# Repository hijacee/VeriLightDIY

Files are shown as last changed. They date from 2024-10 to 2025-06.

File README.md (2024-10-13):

# VeriLightDIY
A DIY Wifi Version of the FinishLynx "VeriLight" that is controllable via the original .lss file. 

## Hardware
You'll need:

- an ESP32 with onboard Wifi, I used an ESP32-WROOM-32U DevKit board from AliExpress
- Some LED Matrices, I used two WS2812b 8x8 5V Grids
- an optional external Wifi antenna to enhance the wifi reception
- an optional mini OLED Screen to see the current configuration, I used an 0.96" OLED Display SSD1306 I2C 128x64 module 4 pin
- an optional momentary push button

## 3D CAD files
The first prototype consists of 4 parts. Feel free to edit, adapt and print those parts for your needs.

- LED_Grid_stl is designed to fit 2 8x8 led matrixes quite tightly
- Cap_Display.stl has a cutout for the OLED display and the wifi antenna with a hexagonal cutout
- ESP_devboard_holder.stl is the middle part to hold the esp loosely in place (upright, USB connector facing downwards), here is definitely room for improvement
- Base_small.stl is the foot/base for the whole setup. In future iterations I could imagine to make this part larger to fit a powerbank directly into the base

## Connection Diagram
Pin 12: Data-Pin LED Matrix
Pin 13: Reset Button
Pin 21: SDA Pin (OLED Screen)
Pin 22: SCL Pin (OLED Screen)

It is very well possible to power the LED Matrices (at least 2x 8x8 Matrices) via the 5V Pin of the ESP. You could also power the matrices directly via a separate +5V source (such as parallel to the the ESP from a USB Powerbank)

The following diagram shows the connectio (note that the LED matrix depicted here is a 4 Pin, I used a 3 Pin with just +5V, GND and DATA).



## How to use the Light
### Network connection
You will need to set up a Wifi network that is also part of the PC you're running FinishLynx on. The Wifi-Router / AccessPoint you are using should be using DHCP to allocate IP addresses to new devices.

On the first start, the Light will go into access point (AP) Mode, as there are no known networks around. It will automatically broadcast an own wifi network named "ReadyLight_AP". Connect to the network with device of your choice - the default passwort is "12345678". Both is adaptable in Line 312 of the code. 
If your device is not directly redirected to the settings page, open a browser and type 192.168.4.1 (as the default Wifi-Manager IP).
The SSID and the IP address of the settings page are also displayed on the OLED display during AP-mode.
In the settings page you can scan for available networks. Chose your network from the list, enter the password if needed and save the configuration. The System will reboot and always connect automatically to the assigned network, if available. It will then also show it's current IP address on the OLED Screen as well as the Port the Light is listening for connection from FinishLynx.

To change the network properties or the FinishLynx Port, you need to re-enter the AP-mode. This is done in pressing the button within three seconds of the boot-up sequence.
If the last configured network is not available, the Light will also boot into AP-mode.



### FinishLynx Setup
The Light is configured as TCP server. To add the Light, follow these steps:
1. In FinishLynx, go to **Scoreboard | Options…**
2. Click **New**.
3. Script: **VeriLight_Ready.lss**
4. Serial Port: **Network(connect)**
   1. Port: **10000** (default, can be changed in the Configuration-Page of the Light, shown on the OLED screen)
   2. IP address: **depending on your network**, shown on the OLED screen
5. Running Time: **Normal**
6. Results: **Off**
7. Click **Ok** and restart FinishLynx.

### Operation
As long as the Light is connected to the network, it will display it's IP address and Port on the OLED display. 
If there is no TCP connection established, the LEDs blink yellow in an one second interval. When FinishLynx connects to that light, the blinking stops and the OLED displays "CLIENT CONNECTED". If, for any reason (network out of range, FinishLynx is closed etc.), the TCP connection breaks, the display says "CLIENT DISCONNECTED" and the LEDs start blinking yellow again. So you an anyone can tell immediately, that something is wrong.

  

The behaviour of the Light is set through the original VeryLight.lss from Finishlynx. You can adapt this lss-script to your needs. In the lss you will find commands that look similar to this:

~~~
;;TimeArmed
\11\00\=0\41\42\44\00\00\07\04\04\04\04\04\01\00
\11\00\=1
~~~

Note that the bytes after `\11\00\=0\` contain the relevant information for the DIY as well as the original VeriLynx Hardware by Patlite. Look in the orignal manual for deeper context: [Patlite LA6-POE Manual](https://docs.rs-online.com/ff50/0900766b8167c578.pdf) 

The seventh byte (in the case above, the first **04**) sets the color for the entire DIY Light according to the following table (same as original Patlite color palette):

| Seventh byte | Color |
| --- | --- |
| 00 | Black (off) |
| 01 | Red |
| 02 | Gold / Amber |
| 03 | Green-Yellow / Lemon |
| 04 | Green |
| 05 | Sky-blue |
| 06 | Blue |
| 07 | Purple |
| 08 | Pink |
| 09 | White |
| other | Black (off) |

Additionaly you can enable blinking of the light with the status of the 12th byte. If it is a **01**, blinking is enabled, if it is a **00**, blinking is disabled. Please note, that currently blinking does not work, when FinishLynx updates the output of the "scoreboard" every second or faster.

## Real life images





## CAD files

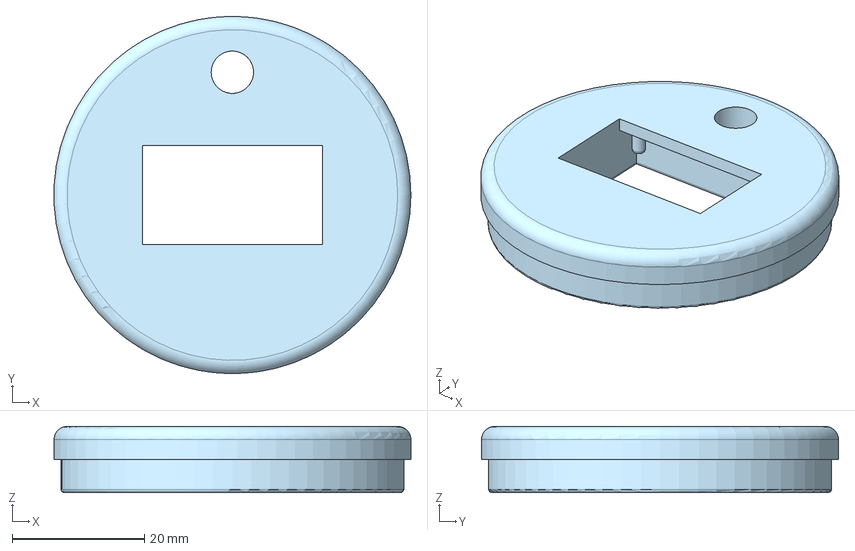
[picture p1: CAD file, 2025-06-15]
CAD_files/STEP/Cap_Display.step
54.0 x 54.0 x 10.0 mm

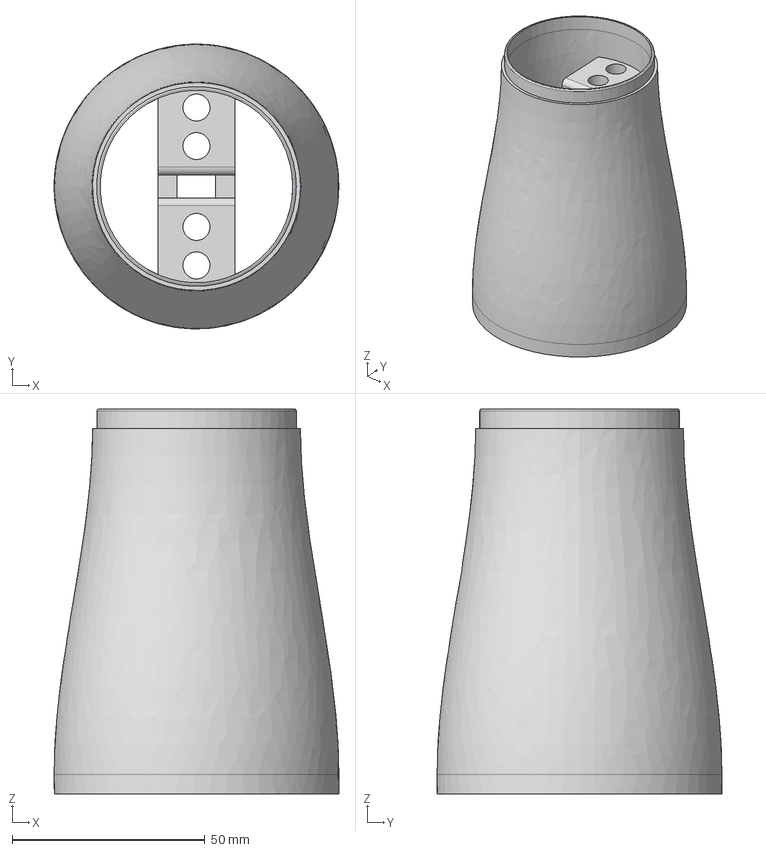
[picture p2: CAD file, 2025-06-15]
CAD_files/STEP/ESP_devboard_holder.step
74.0 x 74.0 x 100.0 mm

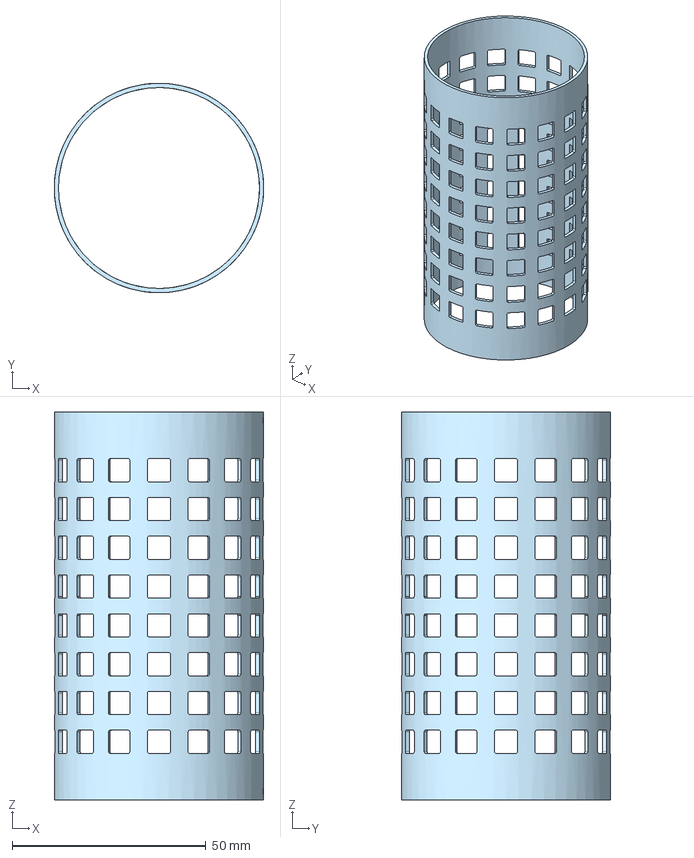
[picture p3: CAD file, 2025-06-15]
CAD_files/STEP/LED_Grid.step
54.0 x 54.0 x 100.0 mm

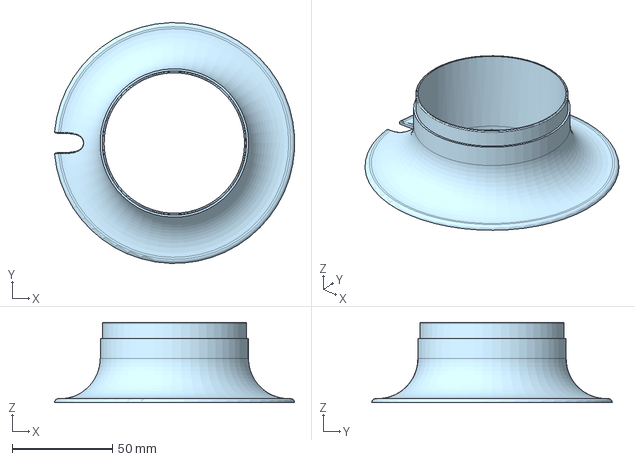
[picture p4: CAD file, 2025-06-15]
CAD_files/STEP/Base_small.step
119.6 x 120.0 x 40.0 mm

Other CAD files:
CAD_files/Base_small.stl
CAD_files/Cap_Display.stl
CAD_files/ESP_devboard_holder.stl
CAD_files/LED_Grid.stl

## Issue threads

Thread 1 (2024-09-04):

Blinking not working in time running / ready

hijacee, 2024-09-04:
The blinking command is not working during time running / ready state. This is due to the reason that the time / command is sent every 0.1 sec from lynx, triggering the function every single time again from start, so the timer does not have the chance to reach the 1 sec blinking interval.

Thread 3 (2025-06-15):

Fusion/Design files

pwae, 2025-06-15:
Hi There!

Love what you have made. I was just hoping if I could get a copy of the CAD files you had, so i can modify a few of the components (without reversing engineering the STL files!).

(e.g. my screen is a bit smaller, and i'm going to use a POE ESP32 board instead of a USB.

Cheers,
Scott

hijacee, 2025-06-15:
Hi Scott!

Thanks!
I provided the STEP files in the CAD folder. However, as I used Onshape instead of Fusion, I do not have native Fusion file formats available. Let me know, if you need another file format.

Cheers,
Christoph

pwae, 2025-06-16:
This is lovely! thank you so much

Scott

Closed 2025-06-16.

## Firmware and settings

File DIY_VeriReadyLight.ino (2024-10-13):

/*
  DIY VeriLight / ReadyLight for FinishLynx
  by Christoph, 2024
  
  Saves data in JSON file on ESP32
  Uses SPIFFS
  
  The Wifi-Manager functions are based on Bills codes at DroneBot Workshop
  https://dronebotworkshop.com/wifimanager/
 
  Functions based upon sketch by Brian Lough
  https://github.com/witnessmenow/ESP32-WiFi-Manager-Examples
*/
#define FASTLED_INTERNAL
 
// Include Libraries
 
#include <WiFi.h>         // WiFi Library
#include <FS.h>           // File System Library
#include <SPIFFS.h>       // SPI Flash Syetem Library
#include <WiFiManager.h>  // WiFiManager Library
#include <ArduinoJson.h>  // Arduino JSON library
#include <FastLED.h>      // LED Matrix Library
#include <Wire.h>         // 2 Wire communication
#include <Adafruit_GFX.h> // Library for Screen
#include <Adafruit_SSD1306.h> // Library for OLED Screen

#define ESP_DRD_USE_SPIFFS true
#define DATA_PIN 12                             // Define LED-Matrix Data Pin
#define TRIGGER_PIN 13                          // Define Wifi-Reset PIN
#define NUM_LEDS 128                            // Define LED-Matrix Data Pin
#define JSON_CONFIG_FILE "/test_config.json"    // JSON configuration file
#define SCREEN_WIDTH 128                        // OLED display width, in pixels
#define SCREEN_HEIGHT 64                        // OLED display height, in pixels
 
// Flag for saving data
bool shouldSaveConfig = false;
 
// Variables to hold data from custom textboxes
char testString[50] = "test value";
int LynxPort = 10000;

// Declaration for an SSD1306 display connected to I2C (SDA, SCL pins)
Adafruit_SSD1306 display(SCREEN_WIDTH, SCREEN_HEIGHT, &Wire, -1);
 

WiFiManager wm;         // Define WiFiManager Object

CRGB leds[NUM_LEDS];    // Define array of LEDs. One item for each LED

WiFiServer server(LynxPort);

const int LED = 14 ;  // Pin der LED
int sizeMsg = 0;
int timeout = 120;    // seconds for AccessPoint to run for after Button Press

// Change to true when testing to force configuration every time we run
bool forceConfig = false;

//timing related variables
unsigned long previousMillis = 0;
const long interval = 1000;  // interval at which to blink (milliseconds)

int colbyte = 0;
int colbytestor = 0;
int blinkbyte = 0;

// Function to light any color depending on 7th bit
void lighton(int a)
{
  for(int i=0;i < NUM_LEDS; i++)
  {
    switch(a) {
      case 0: leds[i] = CRGB::Black;break;
      case 1: leds[i] = CRGB::Red;break;
      case 2: leds[i] = CRGB::Gold;break;        // Instead of "Amber"
      case 3: leds[i] = CRGB::GreenYellow;break; // Instead of "Lemon" 
      case 4: leds[i] = CRGB::Green;break;
      case 5: leds[i] = CRGB::SkyBlue;break;
      case 6: leds[i] = CRGB::Blue;break;
      case 7: leds[i] = CRGB::Purple;break;
      case 8: leds[i] = CRGB::Pink;break;
      case 9: leds[i] = CRGB::White;break;
      default: leds[i] = CRGB::Black;break;
    }
  }

  FastLED.show();

}

//Function to light Matrix yellow middle
void yellowblink() {
  for(int i=0;i < NUM_LEDS; i = i+2)
  {
    leds[i] = CRGB::Yellow;
  }

  FastLED.show();
  delay(1000);
  FastLED.clear();
  FastLED.show();
  delay(1000);
}
 
void saveConfigFile()
// Save Config in JSON format
{
  Serial.println(F("Saving configuration..."));
  
  // Create a JSON document
  JsonDocument json;
  json["testString"] = testString;
  json["LynxPort"] = LynxPort;
 
  // Open config file
  File configFile = SPIFFS.open(JSON_CONFIG_FILE, "w");
  if (!configFile)
  {
    // Error, file did not open
    Serial.println("failed to open config file for writing");
  }
 
  // Serialize JSON data to write to file
  serializeJsonPretty(json, Serial);
  if (serializeJson(json, configFile) == 0)
  {
    // Error writing file
    Serial.println(F("Failed to write to file"));
  }
  // Close file
  configFile.close();
}
 
bool loadConfigFile()
// Load existing configuration file
{
  // Uncomment if we need to format filesystem
  // SPIFFS.format();
 
  // Read configuration from FS json
  Serial.println("Mounting File System...");
 
  // May need to make it begin(true) first time you are using SPIFFS
  if (SPIFFS.begin(false) || SPIFFS.begin(true))
  {
    Serial.println("mounted file system");
    if (SPIFFS.exists(JSON_CONFIG_FILE))
    {
      // The file exists, reading and loading
      Serial.println("reading config file");
      File configFile = SPIFFS.open(JSON_CONFIG_FILE, "r");
      if (configFile)
      {
        Serial.println("Opened configuration file");
        JsonDocument json;
        DeserializationError error = deserializeJson(json, configFile);
        serializeJsonPretty(json, Serial);
        if (!error)
        {
          Serial.println("Parsing JSON");
 
          strcpy(testString, json["testString"]);
          LynxPort = json["LynxPort"].as<int>();
 
          return true;
        }
        else
        {
          // Error loading JSON data
          Serial.println("Failed to load json config");
        }
      }
    }
  }
  else
  {
    // Error mounting file system
    Serial.println("Failed to mount FS");
  }
 
  return false;
}
 
 
void saveConfigCallback()
// Callback notifying us of the need to save configuration
{
  Serial.println("Should save config");
  shouldSaveConfig = true;
}
 
void configModeCallback(WiFiManager *myWiFiManager)
// Called when config mode launched
{
  Serial.println("Entered Configuration Mode");
 
  Serial.print("Config SSID: ");
  Serial.println(myWiFiManager->getConfigPortalSSID());
 
  Serial.print("Config IP Address: ");
  Serial.println(WiFi.softAPIP());

  display.clearDisplay();
  display.setCursor(0, 0);
  display.println("--------------------");
  display.println("Entered Config. Mode");
  display.println("Config SSID: ");
  display.println(myWiFiManager->getConfigPortalSSID());
  display.println("Config IP: ");
  display.println(WiFi.softAPIP());
  display.display();
}

void setBreakAfterConfig(boolean shouldBreak);
 
void setup()
{
  pinMode(LED,OUTPUT);
  digitalWrite(LED, LOW);
  pinMode(TRIGGER_PIN, INPUT_PULLUP);

  wm.setConfigPortalTimeout(timeout);

  // Setup Serial monitor
  Serial.begin(115200);
  delay(10);
  
  if(!display.begin(SSD1306_SWITCHCAPVCC, 0xBC)) { // Address 0x3D for 128x64 or 0xBC
    Serial.println(F("SSD1306 allocation failed"));
    for(;;);
  }
  delay(2000);
  display.clearDisplay();
  display.setTextSize(1);
  display.setTextColor(WHITE);
  display.setCursor(0, 0);
  display.println("    VeriLight DIY   ");
  display.println("--------------------");
  display.println("Check Configuration");
  display.println("Trigger for next");
  display.println("3 sec");
  display.display();
   
   Serial.println("Check Configuration Trigger for next 3 sec");
         int runtime = millis();
         int starttime = runtime;
         while ((runtime - starttime) < 3000)
         {
             if (digitalRead(TRIGGER_PIN) == LOW)
             {
                 Serial.println("Configuration manually triggered.");

                 display.clearDisplay();
                 display.setTextSize(1);
                 display.setTextColor(WHITE);
                 display.setCursor(0, 0);
                 display.println("    VeriLight DIY   ");
                 display.println("--------------------");
                 display.println("Config. triggered.");
                 display.println("Entering AP-Mode.");
                 display.display();
                   forceConfig = true;
             }
             Serial.print(".");
             display.print(".");
             display.display();
             delay(500);
             runtime = millis();
         }
 
  bool spiffsSetup = loadConfigFile();
  if (!spiffsSetup)
  {
    Serial.println(F("Forcing config mode as there is no saved config"));
    forceConfig = true;
  }
 
  // Explicitly set WiFi mode
  WiFi.mode(WIFI_STA);
 
  // Reset settings (only for development)
  //wm.resetSettings();
 
  // Set config save notify callback
  wm.setSaveConfigCallback(saveConfigCallback);
 
  // Set callback that gets called when connecting to previous WiFi fails, and enters Access Point mode
  wm.setAPCallback(configModeCallback);

  //exit after config instead of connecting
  //wm.setBreakAfterConfig(true);
 
  // Custom elements
 
  // Text box (String) - 50 characters maximum
  WiFiManagerParameter custom_text_box("key_text", "Enter your string here", testString, 50);
  
  // Need to convert numerical input to string to display the default value.
  char convertedValue[6];
  sprintf(convertedValue, "%d", LynxPort); 
  
  // Text box (Number) - 5 characters maximum
  WiFiManagerParameter custom_text_box_num("key_num", "Communication Port", convertedValue, 5); 
 
  // Add all defined parameters
  wm.addParameter(&custom_text_box);
  wm.addParameter(&custom_text_box_num);
 
  if (forceConfig)
    // Run if we need a configuration
  {
    if (!wm.startConfigPortal("ReadyLight_AP", "12345678"))
    {
      Serial.println("failed to connect and hit timeout");
      display.clearDisplay();
      display.setCursor(0, 0);
      display.println("    VeriLight DIY   ");
      display.println("--------------------");
      display.println("failed to connect");
      display.println("and hit timeout");
      display.println("----- RESTART -----");
      display.display();
      delay(3000);
      //reset and try again, or maybe put it to deep sleep
      ESP.restart();
      delay(5000);
    }
  }
  else
  {
    if (!wm.autoConnect("ReadyLight_AP", "12345678"))
    {
      Serial.println("failed to connect and hit timeout");
      display.clearDisplay();
      display.setCursor(0, 0);
      display.println("    VeriLight DIY   ");
      display.println("--------------------");
      display.println("failed to connect");
      display.println("and hit timeout");
      display.println("----- RESTART -----");
      display.display();
      delay(3000);
      // if we still have not connected restart and try all over again
      ESP.restart();
      delay(5000);
    }
  }
 
  // If we get here, we are connected to the WiFi
 
  Serial.println("");
  Serial.println("WiFi connected");
  Serial.print("IP address: ");
  Serial.println(WiFi.localIP());

  display.clearDisplay();
  display.setCursor(0, 0);
  display.println("    VeriLight DIY   ");
  display.println("--------------------");
  display.print("IP: ");
  display.println(WiFi.localIP());
  display.print("Port: ");
  display.println(LynxPort);
  display.display();
  
  server.begin(LynxPort);
 
  // Lets deal with the user config values
 
  // Copy the string value
  strncpy(testString, custom_text_box.getValue(), sizeof(testString));
  Serial.print("testString: ");
  Serial.println(testString);
 
  //Convert the number value
  LynxPort = atoi(custom_text_box_num.getValue());
  Serial.print("LynxPort: ");
  Serial.println(LynxPort);
 
 
  // Save the custom parameters to FS
  if (shouldSaveConfig)
  {
    saveConfigFile();
    ESP.restart();
  }

FastLED.addLeds<WS2812B, DATA_PIN, GRB>(leds, NUM_LEDS);  // Initialize LED Matrix - GRB ordering is typical

}
 
 
 
 
void loop() {

   WiFiClient client = server.available();    // Listen for incoming clients
   yellowblink();

    if (client) {                             // If a new client connects,
      if (client.connected()) {
        Serial.println("Client connected.");  // print a message out in the serial port
        display.clearDisplay();
        display.setCursor(0, 0);
        display.println("    VeriLight DIY   ");
        display.println("--------------------");
        display.print("IP: ");
        display.println(WiFi.localIP());
        display.print("Port: ");
        display.println(LynxPort);
        display.println("--------------------");
        display.println("  CLIENT CONNECTED  ");
        display.display();
        FastLED.clear();
        FastLED.show();
      }
      while (true) {                          // loop while the client's connected   
        if (client.available()) 
        {
          delay(10);                            // delay to allow all bytes to be transferred
          sizeMsg = client.available();         // number of bytes transferred
          char charArray[sizeMsg];            // create array with the size of bytes (-1 because array starts with 0) --> That makes no sense, as the size does not get counted
         
          Serial.print("I received: ");
          Serial.print(sizeMsg);
          Serial.println(" bytes.");
      
          for (int i=0; i < sizeMsg; i++)     // for-loop to fill the array wiht the transferred bytes
            {
              charArray[i] = client.read();     // fill the array
        
              Serial.print("Byte ");
              Serial.print(i+1);
              Serial.print(": ");
              Serial.println(charArray[i], HEX);  //print out the content of the array at i
           }
           if (sizeMsg > 7)
           {
            colbyte = charArray[6];                   // convert 7th byte into int
            colbytestor = charArray[6];               // create a colbytestorage for blinking
            Serial.print("The 7th bit is: ");
            Serial.print(colbyte);
            if (sizeMsg > 12)
            {
              blinkbyte = charArray[12];
              Serial.print("The blinkbit is: ");
              Serial.print(blinkbyte);
            }
           }
           else
           {
            Serial.println("Msg smaller than 7 byte - LED off."); //Wenn Initialisiert wird, die Zeit läuft oder pausiert ist (weniger als 7 bytes), keine Freigabe; d.h. ABC000
            digitalWrite(LED, LOW);
            colbyte = 0;
           }
           
        }
        unsigned long currentMillis = millis();
          
        if (blinkbyte == 1)               // check if the blinkbyte is 1
        {
          if (currentMillis - previousMillis >= interval)
          {
            previousMillis = currentMillis;
            if (colbyte == colbytestor)
            {
              colbyte = 0;
            }
            else
            {
              colbyte = colbytestor;
            }
              lighton(colbyte);
           }
        }
         else
         {
           lighton(colbyte);                         // call lighton function, color dependend on 7th byte, blinking dependend on 13th byte (off by default)
         }
          
        
        
      if (!client.connected())                        // if the client disconnects
      {
        Serial.println("Client disconnected.");
        display.clearDisplay();
        display.setCursor(0, 0);
        display.println("    VeriLight DIY   ");
        display.println("--------------------");
        display.print("IP: ");
        display.println(WiFi.localIP());
        display.print("Port: ");
        display.println(LynxPort);
        display.println("--------------------");
        display.println(" CLIENT DISCONNECTED");
        display.display();
        client.stop();                            // stop the client funtion
        digitalWrite(LED, LOW);                   // turn out the LED
        FastLED.clear();
        FastLED.show();
        break;                                    // leave the for loop to be ready for new connection 
      }
     }  
    }    
 
}
